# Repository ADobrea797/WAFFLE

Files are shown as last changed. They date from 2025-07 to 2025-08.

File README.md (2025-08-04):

# WAFFLE
Design, manufacture and assembly files for the WAFFLE instrument.
waffle

**Full assembly instructions can be found in the 'Waffle - Assembly Information.pdf' above.**

**SAFETY WARNING**
The mp-6 micropump operates at high voltage which can pose a serious threat to life. The same applies to the valves which require high current to open. Extreme caution must be exercised when handling those components and their drivers. Please read through the safety datasheets of these components before attempting to build and operate this system on your own.

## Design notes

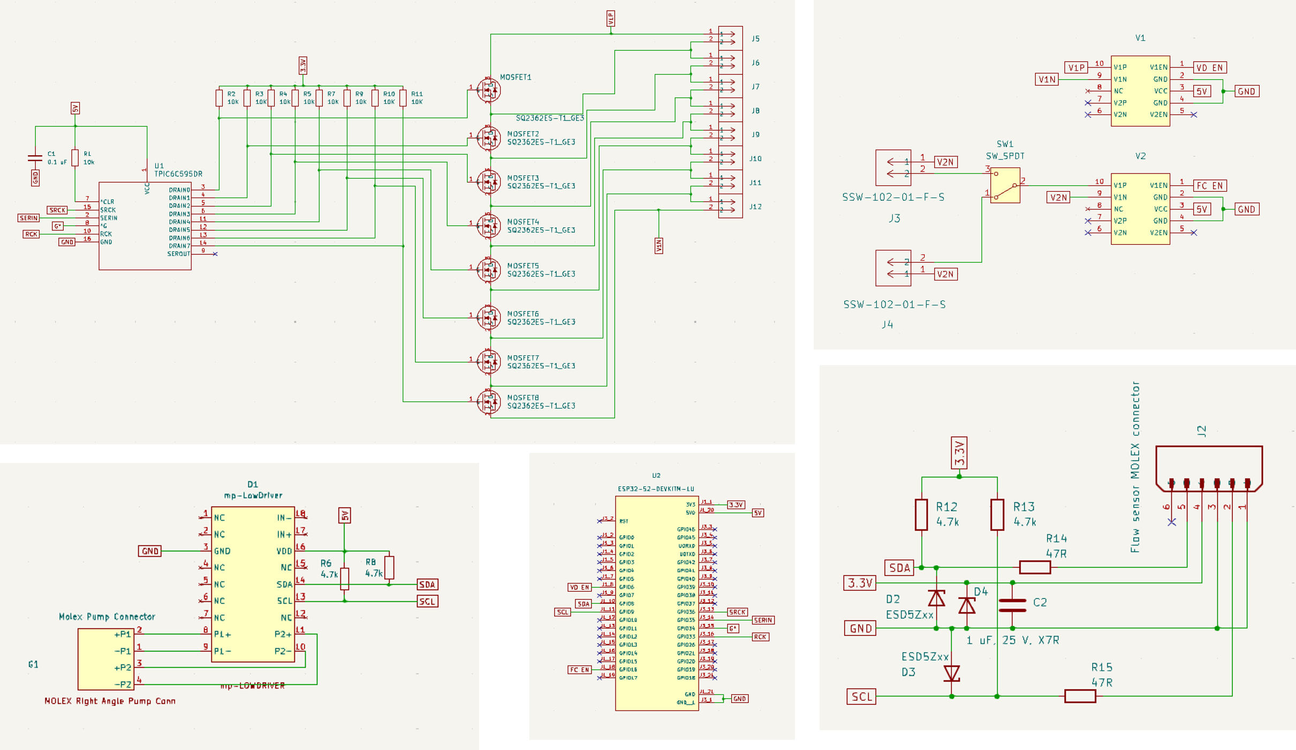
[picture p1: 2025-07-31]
PCBA Files/Electronic schematics.png

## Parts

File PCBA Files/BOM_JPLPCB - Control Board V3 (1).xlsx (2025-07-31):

Comment | Designator | Footprint | JLCPCB Part # | Qty
0.1 uF | C1 | 0402 | C1525 | 1
1 uF | C2 | 0603 | C59302 | 1
ESD5Zxx | D2,D3,D4 | SOD-523 | C343989 | 3
SQ2362ES-T1_GE3 | MOSFET1,MOSFET2,MOSFET3,MOSFET4,MOSFET5,MOSFET6,MOSFET7,MOSFET8 | SOT-23-3(TO-236-3) | C3290054 | 8
10k | R1,R2,R3,R4,R5,R7,R9,R10,R11 | 0402 | C25744 | 1
4.7k | R6,R8,R12,R13 | 0603 | C23162 | 4
47R | R14,R15 | 0603 | C23182 | 2
TPIC6C595DR | U1 | SOIC-16 | C350572 | 1

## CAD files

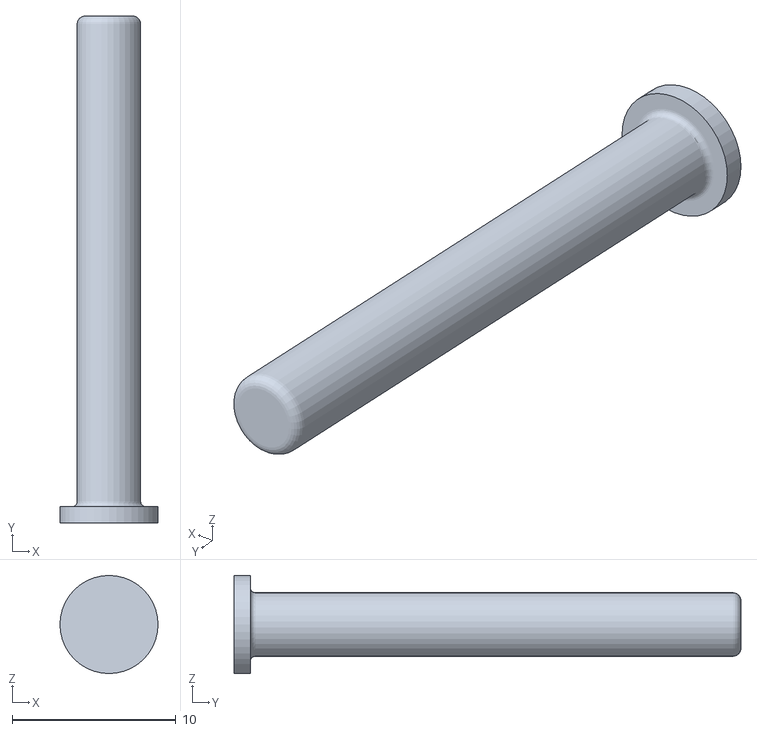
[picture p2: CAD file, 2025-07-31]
STL files/Electrode connector dowel pin.stl
6.00 x 31.0 x 6.00

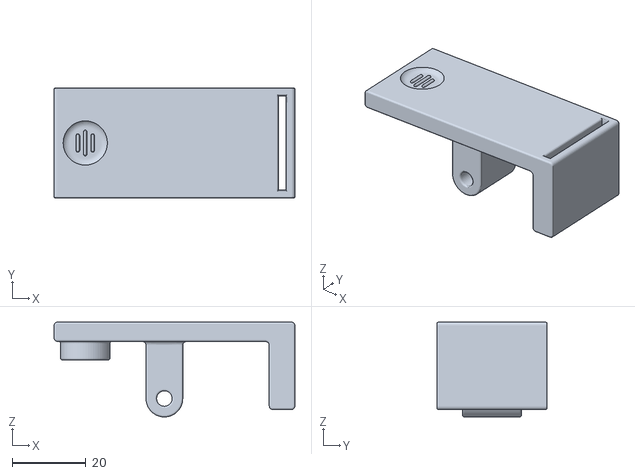
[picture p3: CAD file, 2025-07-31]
STL files/Electrode connector top.stl
65.5 x 30.0 x 25.8

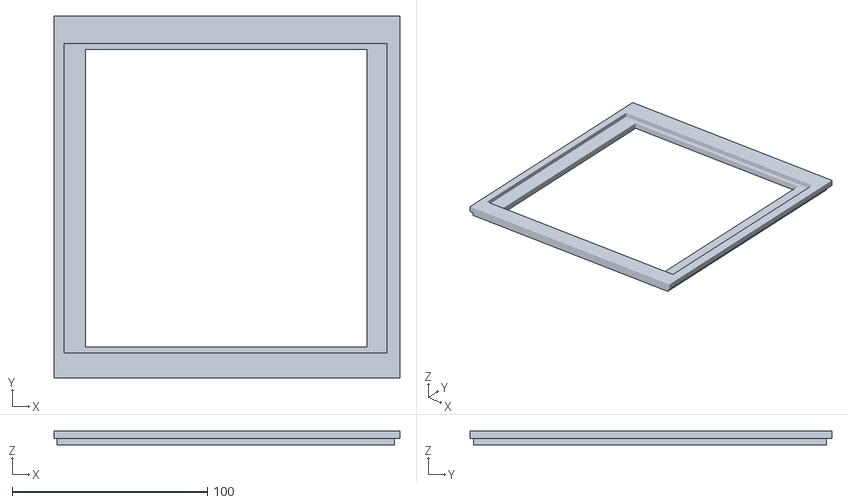
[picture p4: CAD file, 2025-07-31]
STL files/Fluidics chamber - lid.stl
177.0 x 185.0 x 7.30

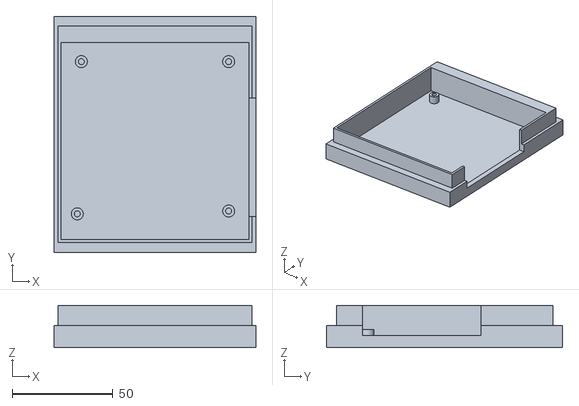
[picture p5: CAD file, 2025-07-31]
STL files/WAFFLE - PCB chamber.stl
100.0 x 116.9 x 21.0

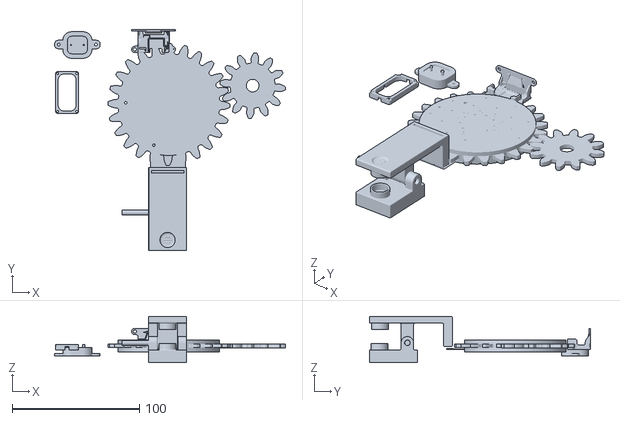
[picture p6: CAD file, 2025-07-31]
STL files/Matching gear.stl
181.9 x 174.3 x 36.3

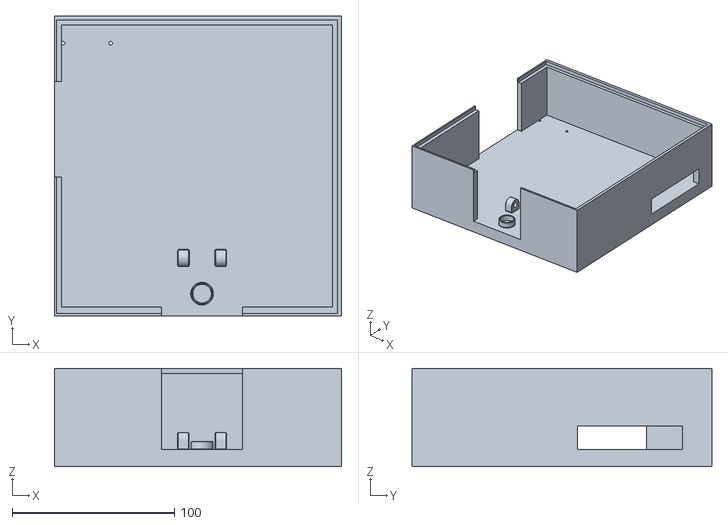
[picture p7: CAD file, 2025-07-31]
STL files/WAFFLE - Fluidics chamber.stl
177.0 x 184.9 x 60.4

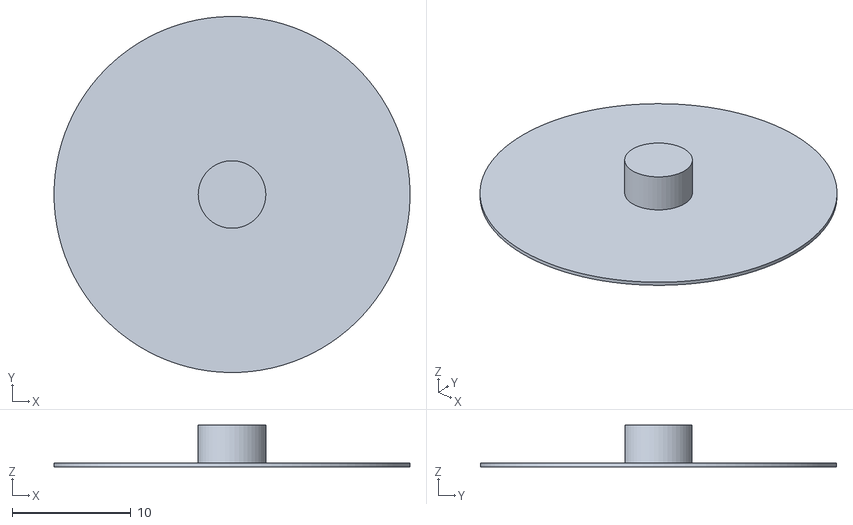
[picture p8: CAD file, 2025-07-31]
STL files/Mounting point for reagent carousel.stl
30.0 x 30.0 x 3.50

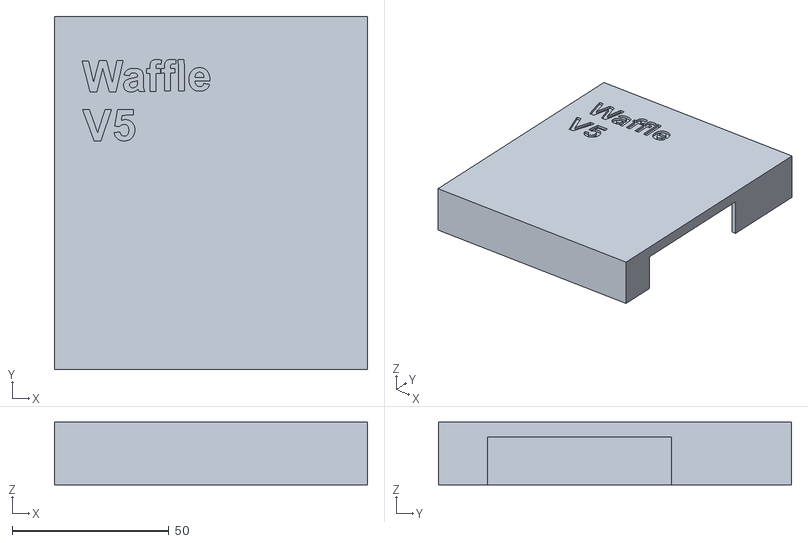
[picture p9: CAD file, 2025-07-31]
STL files/PCB Chamber - Lid.stl
100.0 x 112.9 x 20.0

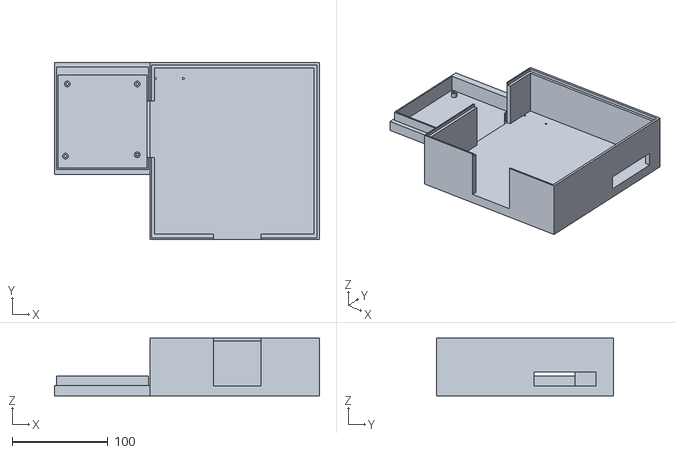
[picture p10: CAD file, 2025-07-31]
STL files/WAFFLE - PCB and fluidics chamber.stl
277.0 x 184.9 x 60.4

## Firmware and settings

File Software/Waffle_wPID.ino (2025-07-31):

#include <WiFi.h>
#include <SPI.h>
#include <Wire.h>
#include <AsyncTCP.h>
#include <ESPAsyncWebServer.h>
#include "sensirion-lf.h"
#include <PID_v1.h>  // Include the Arduino PID library

// Network credentials
const char* ssid = "XXX"; //Replace with network name
const char* password = "XXX";//Replace with network password

// Web server
AsyncWebServer server(80);

// Shift register pins
const int dataPin = 35;
const int latchPin = 36;
const int slaveSelectPin = 33;
const int outputEnablePin = 34;
const int valveEnablePin = 6; 
const int flowcellEnablePin = 16; 
unsigned long lastVoltageUpdateTime = 0;  // Track last update time
const unsigned long voltageUpdateInterval = 200;  // Interval for voltage updates (in ms)

const int numReadings = 10;   // Number of readings for the moving average
double flowReadings[numReadings]; // Array to store flow readings
int readIndex = 0;             // Current index in the array
double totalFlow = 0;          // Sum of the readings
double averageFlow = 0;        // Moving average of the readings

// Valve states
bool output26State = false;
bool output27State = false;
bool output28State = false;
bool output29State = false;
bool output30State = false;
bool output31State = false;
bool output32State = false;
bool output33State = false;
bool flowcellEnableState = false; 

// Pump control variables
boolean bPumpState = false;
uint8_t nPumpVoltageByte = 0x00;
uint16_t currentFrequency = 100; // Locked frequency at 100 Hz (may be changed if needed)

#define I2C_LOWDRIVER_ADRESS (0x59)

// PID control variables
double flowSetpoint = 0;
double currentFlow = 0;
double pidOutput = 0;
double kp = 5, ki = 15, kd = 1;

// Initialize the PID controller
PID myPID(&currentFlow, &pidOutput, &flowSetpoint, kp, ki, kd, DIRECT);

// Function declarations
void Lowdriver_setvoltage(uint8_t _voltage);
void Lowdriver_setfrequency(uint16_t frequency);
void Lowdriver_init();
void updateShiftRegister();

// Sensirion flow sensor settings
#define MEASURE_DELAY 100


// GUI HTML Webpage design
const char index_html[] PROGMEM = R"rawliteral(
<!DOCTYPE HTML><html>
<head>
  <meta name="viewport" content="width=device-width, initial-scale=1">
  <title>ESP Web Server</title>
  <style>
    html {font-family: Arial; display: inline-block; text-align: center;}
    h2 {font-size: 1.84rem;}
    p {font-size: 1.52rem;}
    body {max-width: 400px; margin:0px auto; padding-bottom: 25px;}
    .button { background-color: #4CAF50; border: none; color: white; padding: 12.8px 32px;
      text-decoration: none; font-size: 24px; margin: 1.6px; cursor: pointer; }
    .button2 { background-color: #555555; }
    .slider { -webkit-appearance: none; margin: 14px; width: 360px; height: 25px; border-radius: 5px; background: #FFD65C;
      outline: none; -webkit-transition: .2s; transition: opacity .2s;}
    .checkbox { margin-top: 20px; }
    .flow-container { color: grey; }
    .flow-value { background-color: #d3d3d3; padding: 0 5px; border-radius: 3px; }
  </style>
</head>
<body>
  <h2>ESP Web Server</h2>
  <p>Flow rate: <span id="flowValue" class="flow-value">%FLOWVALUE%</span> ml/min</p>
  <p>Flow rate Setpoint: <input type="number" id="flowSetpointInput" min="0" step="0.1" value="%FLOWSETPOINT%" onchange="updateFlowSetpoint(this)"></p>
  <p>Enable Pump: <input type="checkbox" id="pumpCheckbox" class="checkbox" onchange="togglePump(this)" %PUMPSTATE%></p>
  <p>Valve 1 - State: <span id="state26">%STATE26%</span></p>
  <p><a href="/26/%TOGGLE26%"><button class="button %BTN26%">%BTNTEXT26%</button></a></p>
  <p>Valve 2 - State: <span id="state27">%STATE27%</span></p>
  <p><a href="/27/%TOGGLE27%"><button class="button %BTN27%">%BTNTEXT27%</button></a></p>
  <p>Valve 3 - State: <span id="state28">%STATE28%</span></p>
  <p><a href="/28/%TOGGLE28%"><button class="button %BTN28%">%BTNTEXT28%</button></a></p>
  <p>Valve 4 - State: <span id="state29">%STATE29%</span></p>
  <p><a href="/29/%TOGGLE29%"><button class="button %BTN29%">%BTNTEXT29%</button></a></p>
  <p>Valve 5 - State: <span id="state30">%STATE30%</span></p>
  <p><a href="/30/%TOGGLE30%"><button class="button %BTN30%">%BTNTEXT30%</button></a></p>
  <p>Valve 6 - State: <span id="state31">%STATE31%</span></p>
  <p><a href="/31/%TOGGLE31%"><button class="button %BTN31%">%BTNTEXT31%</button></a></p>
  <p>Valve 7 - State: <span id="state32">%STATE32%</span></p>
  <p><a href="/32/%TOGGLE32%"><button class="button %BTN32%">%BTNTEXT32%</button></a></p>
  <p>Valve 8 - State: <span id="state33">%STATE33%</span></p>
  <p><a href="/33/%TOGGLE33%"><button class="button %BTN33%">%BTNTEXT33%</button></a></p>
  <p>Flowcell Enable 1 - State: <span id="stateFlowcell">%STATEFLOWCELL%</span></p>
  <p><a href="/flowcell/%TOGGLEFLOWCELL%"><button class="button %BTNFlowcell%">%BTNTEXTFLOWCELL%</button></a></p>

<script>

function updateFlowSetpoint(element) {
  var flowSetpoint = element.value;
  var xhr = new XMLHttpRequest();
  xhr.open("GET", "/setflowsetpoint?flowSetpoint=" + flowSetpoint, true);
  xhr.send();
}

function togglePump(element) {
  var pumpState = element.checked ? "on" : "off";
  var xhr = new XMLHttpRequest();
  xhr.open("GET", "/setpump?state=" + pumpState, true);
  xhr.send();
}

</script>
</body>
</html>
)rawliteral";

// Replaces placeholder with dynamic values
String processor(const String& var) {
  if (var == "FLOWVALUE") return String(currentFlow, 2);
  if (var == "FLOWSETPOINT") return String(flowSetpoint, 2);
  if (var == "PUMPSTATE") return String(bPumpState ? "checked" : "");
  
  if (var == "STATE26") return String(output26State ? "ON" : "OFF");
  if (var == "TOGGLE26") return String(output26State ? "off" : "on");
  if (var == "BTN26") return String(output26State ? "button2" : "button");
  if (var == "BTNTEXT26") return String(output26State ? "OFF" : "ON");
  if (var == "STATE27") return String(output27State ? "ON" : "OFF");
  if (var == "TOGGLE27") return String(output27State ? "off" : "on");
  if (var == "BTN27") return String(output27State ? "button2" : "button");
  if (var == "BTNTEXT27") return String(output27State ? "OFF" : "ON");
  if (var == "STATE28") return String(output28State ? "ON" : "OFF");
  if (var == "TOGGLE28") return String(output28State ? "off" : "on");
  if (var == "BTN28") return String(output28State ? "button2" : "button");
  if (var == "BTNTEXT28") return String(output28State ? "OFF" : "ON");
  if (var == "STATE29") return String(output29State ? "ON" : "OFF");
  if (var == "TOGGLE29") return String(output29State ? "off" : "on");
  if (var == "BTN29") return String(output29State ? "button2" : "button");
  if (var == "BTNTEXT29") return String(output29State ? "OFF" : "ON");
  if (var == "STATE30") return String(output30State ? "ON" : "OFF");
  if (var == "TOGGLE30") return String(output30State ? "off" : "on");
  if (var == "BTN30") return String(output30State ? "button2" : "button");
  if (var == "BTNTEXT30") return String(output30State ? "OFF" : "ON");
  if (var == "STATE31") return String(output31State ? "ON" : "OFF");
  if (var == "TOGGLE31") return String(output31State ? "off" : "on");
  if (var == "BTN31") return String(output31State ? "button2" : "button");
  if (var == "BTNTEXT31") return String(output31State ? "OFF" : "ON");
  if (var == "STATE32") return String(output32State ? "ON" : "OFF");
  if (var == "TOGGLE32") return String(output32State ? "off" : "on");
  if (var == "BTN32") return String(output32State ? "button2" : "button");
  if (var == "BTNTEXT32") return String(output32State ? "OFF" : "ON");
  if (var == "STATE33") return String(output33State ? "ON" : "OFF");
  if (var == "TOGGLE33") return String(output33State ? "off" : "on");
  if (var == "BTN33") return String(output33State ? "button2" : "button");
  if (var == "BTNTEXT33") return String(output33State ? "OFF" : "ON");

  if (var == "STATEFLOWCELL") return String(flowcellEnableState ? "ON" : "OFF"); // New placeholder
  if (var == "TOGGLEFLOWCELL") return String(flowcellEnableState ? "off" : "on"); // New placeholder
  if (var == "BTNFlowcell") return String(flowcellEnableState ? "button2" : "button"); // New placeholder
  if (var == "BTNTEXTFLOWCELL") return String(flowcellEnableState ? "OFF" : "ON"); // New placeholder
  return String();
}

void setup() {

  // Initialize array to 0
    for (int i = 0; i < numReadings; i++) {
        flowReadings[i] = 0;
    }
    totalFlow = 0;
    
  // Initialize the output variables as outputs
  pinMode(dataPin, OUTPUT);
  pinMode(latchPin, OUTPUT);
  pinMode(slaveSelectPin, OUTPUT);
  pinMode(valveEnablePin, OUTPUT); 
  pinMode(outputEnablePin, OUTPUT); 
  pinMode(flowcellEnablePin, OUTPUT);  

 digitalWrite(outputEnablePin, HIGH); // Initially disable the outputs
  digitalWrite(flowcellEnablePin, LOW); // Initially disable the flowcell

  Serial.begin(115200); // initialize serial communication
  if (SLF3X.init() != 0) {
    Serial.println("Error during SLF3X init. Stopping application.");
    while (1) { 
       Serial.println("Retrying SLF3X initialization...");
       delay(1000); 
       if (SLF3X.init() == 0) break;  // Try re-initializing} // loop forever
  }
}
  SPI.begin();
  digitalWrite(slaveSelectPin, LOW);

  Serial.print("Connecting to ");
  Serial.println(ssid);
  WiFi.begin(ssid, password);
  while (WiFi.status() != WL_CONNECTED) {
    delay(500);
    Serial.print(".");
  }
  Serial.println("");
  Serial.println("WiFi connected.");
  Serial.println("IP address: ");
  Serial.println(WiFi.localIP());



  
  // Web server handlers
  server.on("/", HTTP_GET, [](AsyncWebServerRequest *request) {
    request->send_P(200, "text/html", index_html, processor);
  });

  server.on("/setflowsetpoint", HTTP_GET, [](AsyncWebServerRequest *request) {
    if (request->hasParam("flowSetpoint")) {
      flowSetpoint = request->getParam("flowSetpoint")->value().toFloat();
      Serial.println("Flow Setpoint: " + String(flowSetpoint));
    }
    request->send(200, "text/plain", "OK");
  });

  server.on("/setpump", HTTP_GET, [](AsyncWebServerRequest *request) {
    String inputMessage = request->getParam("state")->value();
    bPumpState = (inputMessage == "on");
    if (!bPumpState) Lowdriver_setvoltage(0);  // Turn off pump if disabled
    Serial.println("Pump State: " + String(bPumpState ? "ON" : "OFF"));
    request->send(200, "text/plain", "OK");
  });


  server.on("/26/on", HTTP_GET, [](AsyncWebServerRequest *request) {
    output26State = true;
    updateShiftRegister();
    delay(1000);
    digitalWrite(valveEnablePin, HIGH);
    Serial.println("Valve 1 State: ON");
    request->redirect("/");
  });

  server.on("/26/off", HTTP_GET, [](AsyncWebServerRequest *request) {
    output26State = false;
    digitalWrite(valveEnablePin, LOW);
    Serial.println("Valve 1 State: OFF");
    delay(1000);
    updateShiftRegister();
    request->redirect("/");
  });

  server.on("/27/on", HTTP_GET, [](AsyncWebServerRequest *request) {
    output27State = true;
    updateShiftRegister();
    delay(1000);
    digitalWrite(valveEnablePin, HIGH);
    Serial.println("Valve 2 State: ON");
    request->redirect("/");
  });

  server.on("/27/off", HTTP_GET, [](AsyncWebServerRequest *request) {
    output27State = false;
    digitalWrite(valveEnablePin, LOW);
    Serial.println("Valve 2 State: OFF");
    delay(1000);
    updateShiftRegister();
    request->redirect("/");
  });

  server.on("/28/on", HTTP_GET, [](AsyncWebServerRequest *request) {
    output28State = true;
    updateShiftRegister();
    delay(1000);
    digitalWrite(valveEnablePin, HIGH);
    Serial.println("Valve 3 State: ON");
    request->redirect("/");
  });

  server.on("/28/off", HTTP_GET, [](AsyncWebServerRequest *request) {
    output28State = false;
    digitalWrite(valveEnablePin, LOW);
    Serial.println("Valve 3 State: OFF");
    delay(1000);
    updateShiftRegister();
    request->redirect("/");
  });

  server.on("/29/on", HTTP_GET, [](AsyncWebServerRequest *request) {
    output29State = true;
    updateShiftRegister();
    delay(1000);
    digitalWrite(valveEnablePin, HIGH);
    Serial.println("Valve 4 State: ON");
    request->redirect("/");
  });

  server.on("/29/off", HTTP_GET, [](AsyncWebServerRequest *request) {
    output29State = false;
    digitalWrite(valveEnablePin, LOW);
    Serial.println("Valve 4 State: OFF");
    delay(1000);
    updateShiftRegister();
    request->redirect("/");
  });

  server.on("/30/on", HTTP_GET, [](AsyncWebServerRequest *request) {
    output30State = true;
    updateShiftRegister();
    delay(1000);
    digitalWrite(valveEnablePin, HIGH);
    Serial.println("Valve 5 State: ON");
    request->redirect("/");
  });

  server.on("/30/off", HTTP_GET, [](AsyncWebServerRequest *request) {
    output30State = false;
    digitalWrite(valveEnablePin, LOW);
    Serial.println("Valve 5 State: OFF");
     delay(1000);

       updateShiftRegister();
    request->redirect("/");
  });

  server.on("/31/on", HTTP_GET, [](AsyncWebServerRequest *request) {
    output31State = true;
    updateShiftRegister();
    delay(1000);
    digitalWrite(valveEnablePin, HIGH);
    Serial.println("Valve 6 State: ON");
    request->redirect("/");
  });

  server.on("/31/off", HTTP_GET, [](AsyncWebServerRequest *request) {
    output31State = false;
    digitalWrite(valveEnablePin, LOW);
    Serial.println("Valve 6 State: OFF");
    delay(1000);
    updateShiftRegister();
    request->redirect("/");
  });

  server.on("/32/on", HTTP_GET, [](AsyncWebServerRequest *request) {
    output32State = true;
    updateShiftRegister();
    delay(1000);
    digitalWrite(valveEnablePin, HIGH);
    Serial.println("Valve 7 State: ON");
    request->redirect("/");
  });

  server.on("/32/off", HTTP_GET, [](AsyncWebServerRequest *request) {
    output32State = false;
    digitalWrite(valveEnablePin, LOW);
    Serial.println("Valve 7 State: OFF");
    delay(1000);
    updateShiftRegister();
    request->redirect("/");
  });

  server.on("/33/on", HTTP_GET, [](AsyncWebServerRequest *request){
    output33State = true;
    updateShiftRegister();
    delay(1000);
    digitalWrite(valveEnablePin, HIGH);
    Serial.println("Valve 8 State: ON");
    request->redirect("/");
  });

  server.on("/33/off", HTTP_GET, [](AsyncWebServerRequest *request) {
    output33State = false;
    digitalWrite(valveEnablePin, LOW);
    Serial.println("Valve 8 State: OFF");
    delay(1000);
    updateShiftRegister();
    request->redirect("/");
  });

  server.on("/flowcell/on", HTTP_GET, [](AsyncWebServerRequest *request) {
    flowcellEnableState = true;
    digitalWrite(flowcellEnablePin, HIGH);
    Serial.println("Flowcell Enable 1 State: ON");
    request->redirect("/");
  });

  server.on("/flowcell/off", HTTP_GET, [](AsyncWebServerRequest *request) {
    flowcellEnableState = false;
    digitalWrite(flowcellEnablePin, LOW);
    Serial.println("Flowcell Enable 1 State: OFF");
    request->redirect("/");
  });

  server.begin();
  Lowdriver_init();

   // Initialize PID controller settings
  myPID.SetMode(AUTOMATIC);
  myPID.SetOutputLimits(0, 150);  // Limit output to lowdriver voltage range (0 to 150V)

// Set initial pump conditions for stable flow
  Lowdriver_setvoltage(150);  // Set initial voltage to 150V
  Lowdriver_setfrequency(100); // Set initial frequency to 100Hz
  delay(5000); // Allow time for the flow to stabilize

 // Set initial frequency to 100Hz
  Lowdriver_setfrequency(100);


  // Send column headers for PLX-DAQ
  Serial.println("LABEL,Time,Flow Rate (ml/min),Voltage (V)");
}

void updateShiftRegister() {
  byte ledsState = 0b00000000;
  if (output26State) ledsState |= 0b00000001;
  if (output27State) ledsState |= 0b00000010;
  if (output28State) ledsState |= 0b00000100;
  if (output29State) ledsState |= 0b00001000;
  if (output30State) ledsState |= 0b00010000;
  if (output31State) ledsState |= 0b00100000;
  if (output32State) ledsState |= 0b01000000;
  if (output33State) ledsState |= 0b10000000;

  digitalWrite(outputEnablePin, HIGH); // Disable outputs before updating
  digitalWrite(slaveSelectPin, LOW); // << RCLK line goes low
  SPI.transfer(ledsState); // << SRCLK goes high-low 8 times to output 8 bits of data
  digitalWrite(slaveSelectPin, HIGH); // Data outputs change on this rising edge << RCLK line goes high to move data into output register
  digitalWrite(outputEnablePin, LOW); // Enable outputs after updating

  Serial.print("ledsState: ");
  Serial.println(ledsState, BIN); // Print the binary representation of ledsState
}

// Function to select control registers
void selectControlRegisters() {
  Wire.beginTransmission(I2C_LOWDRIVER_ADRESS);
  Wire.write(0xFF);
  Wire.write(0x00);
  Wire.endTransmission();  
}

// Function to select memory registers
void selectMemoryRegisters() {
  Wire.beginTransmission(I2C_LOWDRIVER_ADRESS);
  Wire.write(0xFF);
  Wire.write(0x01);
  Wire.endTransmission();  
}

void Lowdriver_init() {
    selectControlRegisters();
    Wire.beginTransmission(I2C_LOWDRIVER_ADRESS);
    Wire.write(0x01); // Control Register setup
    Wire.write(0x02); // Set Gain
    Wire.write(0x00); // Wake up from standby
    Wire.write(0x01); // Play waveform sequence #1
    Wire.endTransmission();

    selectMemoryRegisters();
    Wire.beginTransmission(I2C_LOWDRIVER_ADRESS);
    Wire.write(0x00); // Start at Register 0x00
    Wire.write(0x05); // Set header size
    Wire.write(0x80); // Mode 3 start address
    Wire.write(0x06); // Start address lower byte
    Wire.write(0x00); // Stop address upper byte
    Wire.write(0x09); // Stop address lower byte
    Wire.write(0x00); // Repeat once
    Wire.write(0x00); // Initial Amplitude 0V
    Wire.write(0x0C); // Initial Frequency 100Hz
    Wire.write(100);  // Duration in cycles
    Wire.write(0x00); // No envelope
    Wire.endTransmission();
    delay(10);

    selectControlRegisters();
    Wire.beginTransmission(I2C_LOWDRIVER_ADRESS);
    Wire.write(0x02); // Set Go bit to start playback
    Wire.write(0x01);
    Wire.endTransmission();

    Serial.println("Lowdriver initialized");
    bPumpState = false;
    nPumpVoltageByte = 255;
}

// Set pump voltage with debugging and reinitialization
void Lowdriver_setvoltage(uint8_t _voltage) {
    Serial.print("Setting voltage to: ");
    Serial.println(_voltage);

    // Scale voltage for low-driver register
    float temp = _voltage;
    temp *= 255;
    temp /= 150;
    nPumpVoltageByte = constrain(temp, 0, 255);

    // Stop waveform playback
    Wire.beginTransmission(I2C_LOWDRIVER_ADRESS);
    Wire.write(0x02);
    Wire.write(0x00);
    Wire.endTransmission();
    delay(10);

    // Set voltage value
    selectMemoryRegisters();
    Wire.beginTransmission(I2C_LOWDRIVER_ADRESS);
    Wire.write(0x06);
    Wire.write((bPumpState ? nPumpVoltageByte : 0));
    Wire.endTransmission();
    delay(10);

    // Restart waveform playback
    selectControlRegisters();
    Wire.beginTransmission(I2C_LOWDRIVER_ADRESS);
    Wire.write(0x02);
    Wire.write(0x01);
    Wire.endTransmission();
    delay(50);

    Serial.print("Voltage set to ");
    Serial.print(_voltage);
    Serial.print("V (Byte: ");
    Serial.print(nPumpVoltageByte);
    Serial.println(")");
}
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
void loop() {
    int ret = SLF3X.readSample();
    if (ret == 0) {
       // Get new flow reading and update moving average
        double newFlowReading = SLF3X.getFlow() * 0.0519 - 0.0122;//determined from sensor calibration, may need to be adapted if a different sensor is used
        updateMovingAverage(newFlowReading);  // Update moving average
        currentFlow = averageFlow;            // Use moving average for PID

        if (bPumpState) {
            Serial.println("Using Setpoint for PID: " + String(flowSetpoint));
            myPID.Compute();
            int roundedVoltage = round(pidOutput);  // Compute voltage from PID

             // Check if enough time has passed to update the voltage
            if (millis() - lastVoltageUpdateTime >= voltageUpdateInterval) {
                Lowdriver_setvoltage(roundedVoltage);  // Set pump voltage
                lastVoltageUpdateTime = millis();  // Update last time
            }
            // Set frequency to a constant value if static (e.g., 100 Hz)
            Lowdriver_setfrequency(100);

            // Display flow and voltage data
            Serial.print("Flow: ");
            Serial.print(currentFlow);
            Serial.print(" ml/min, Setpoint: ");
            Serial.print(flowSetpoint);
            Serial.print(" ml/min, Voltage: ");
            Serial.print(roundedVoltage);
            Serial.println("V");

            // Log data
            Serial.print("DATA,TIME,");
            Serial.print(currentFlow, 2);
            Serial.print(",");
            Serial.println(pidOutput, 2);
        } else {
            Lowdriver_setvoltage(0);
        }

        // Check for sensor alerts
        if (SLF3X.isAirInLineDetected()) Serial.println(" [Air in Line Detected]");
        if (SLF3X.isHighFlowDetected()) Serial.println(" [High Flow Detected]");
    } else {
        Serial.print("Error in SLF3X.readSample(): ");
        Serial.println(ret);
    }
    delay(MEASURE_DELAY);
}
